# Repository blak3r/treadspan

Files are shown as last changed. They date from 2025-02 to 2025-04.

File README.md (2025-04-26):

# TreadSpan (the app for Treadmill Desk User's) 

With your hands stationary on a keyboard, watch based tracking methods don't work.  If your treadmill 
manufacturer offers an app, it requires you to log each session individually. TreadSpan solves this problem
and makes it easy to track all your steps taken from your Treadmill Desk. 

People that work at Treadmill Desks have different needs than those who use a treadmill for running. TreadSpan is the answer.

Everything about this solution is Open Source (mobile app, firmware, and hardware).  Together we can extend TreadSpan to 
support more treadmills. 

## Demo Video
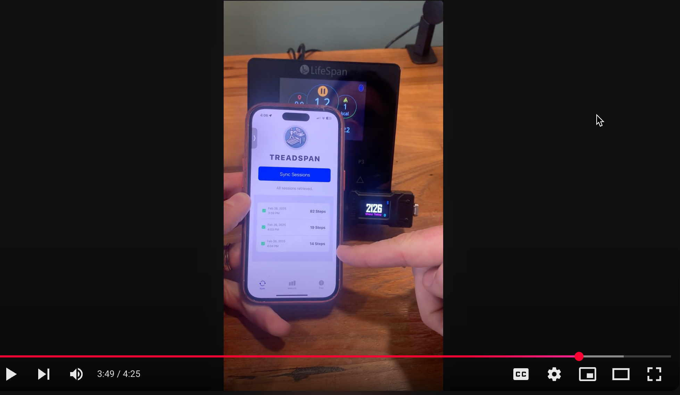
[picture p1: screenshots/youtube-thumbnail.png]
(https://youtu.be/KdCkAAa3uqI)


## My Story

When I upgraded my Treadmill, I purchased the [TR1200](https://amzn.to/4bbn8ok) from LifeSpan Fitness, in part 
because the manufacturer had created a mobile app which would allow you to log your steps and it would integrate with
Apple HealthKit. 
It sounded like the perfect solution. But, unfortunately the implementation of their mobile app was poor to say the least.
The biggest issue, was you had to open their clunky app to sync every session individually. 
Anytime, I went to the bathroom, answered the door, or grabbed a snack, I'd have to open the app, stop my train of 
thought on what i was doing, and log the steps.  I was sorta baffled. My bathroom scale logs my weight each time I step 
on it and stores each entry to it's internal memory. It patiently waits for me to open the mobile app and then it logs
all the unsynced entries to HealthKit in one go.

That's what this project aimed todo.  Make my walking pad as convenient as my bathroom scale. 
And with about $20 and 10 minutes of time, you can set this up too and free your mind from the chore of logging your
steps.

## Instructions

1. Buy this [~$17 ESP32 Module](https://amzn.to/43eFNhn). (See Hardware section for more options)
2. Install the [USB Serial drivers.](https://www.silabs.com/developer-tools/usb-to-uart-bridge-vcp-drivers?tab=downloads)
3. Load TreadSpan firmware / configure wifi, by [opening this page in Chrome](https://blak3r.github.io/treadspan-web-installer/). Support Video here: https://youtu.be/1UJMbb7URYI
5. Install the "TreadSpan" app on your iOS Device from the AppStore.
6. Open the app and follow instructions.

After the firmware is loaded in step 3, you can disconnect the module from your computer and can power it using any 
old USB-C cable/charger you have laying around.  You don't need to have it even visible on your desk, you could stuff it
in a cable tray under your desk if you really wanted to. 

## Hardware

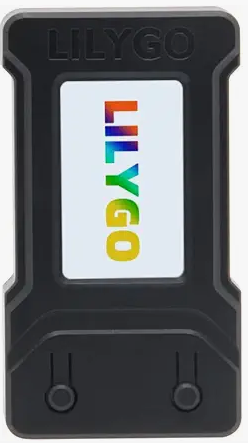
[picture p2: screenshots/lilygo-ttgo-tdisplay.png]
(https://amzn.to/43eFNhn)


* [Option 1: comes with a case - LILYGO ESP32 T-Display Module for Arduino CH9102F Chip TTGO Development Board with Shell Version](https://amzn.to/43eFNhn)
* [Option 2: no case - LILYGO ESP32 T-Display Module for Arduino CH9102F Chip TTGO Development Board NO Case](https://amzn.to/43eFNhn)

The case version has a much longer shipping estimate.  I've ordered it twice and they come within a week despite saying 2-3 weeks.
In Feb 2025, the case version was \$17 + \$9.50 shipping and the no case version is \$20 with free shipping. 
If you have a 3D printer and are impatient you can [print the case from these files](https://github.com/Xinyuan-LilyGO/TTGO-T-Display/tree/master/3d_file). 

If the links provided have gone bad, here is what you're looking to buy.
* Brand: LilyGo
* Chipset: ESPRESSIF-ESP32    <-- Notice it does NOT end with S3
* Model: TTGO T-Display
* Flash: 16MB
* Display: IPS ST7789V 1.14 Inch

DO NOT BUY THESE SIMILAR OPTIONS:
* T-Display-S3 AMOLED ESP32-S3 with 1.91 Inch RM67162 Display TTGO Development Board Wireless Module
* T-Display S3 ESP32-S3 1.9-inch ST7789 LCD Display Touchable Screen TTGO Wireless Module Welding Pin Development Board
* T-Display-S3-Long 16MB Flash ESP32-S3 TTGO Development Board with 3.4-inch Touch Display TFT LCD Wireless Modules

Technically, any ESP32 based Arduino should work.  I have loaded it on Arduino Nano ESP32 and The suggested hardware is nice since it has an LCD on it so it'll 
be helpful if you don't have wifi configured properly... or want to know how many sessions are on the device etc.

## Mobile App Features
- It's a barebones application that fetches all logged sessions from the arduino module aka the chip and adds them to HealthKit.  It does this in one step, no need to do the sync to apple health separately.
- It doesn't require you to create an account / login. No information is shared with 3rd Parties (other then Apple HealthKid)!
- It also has some visualizations that are very similar to the step graphs in Apple Health but it'll break out steps taken on your treadmill  
  vs. steps logged organically through a watch or iphone.

<table>
<tr>
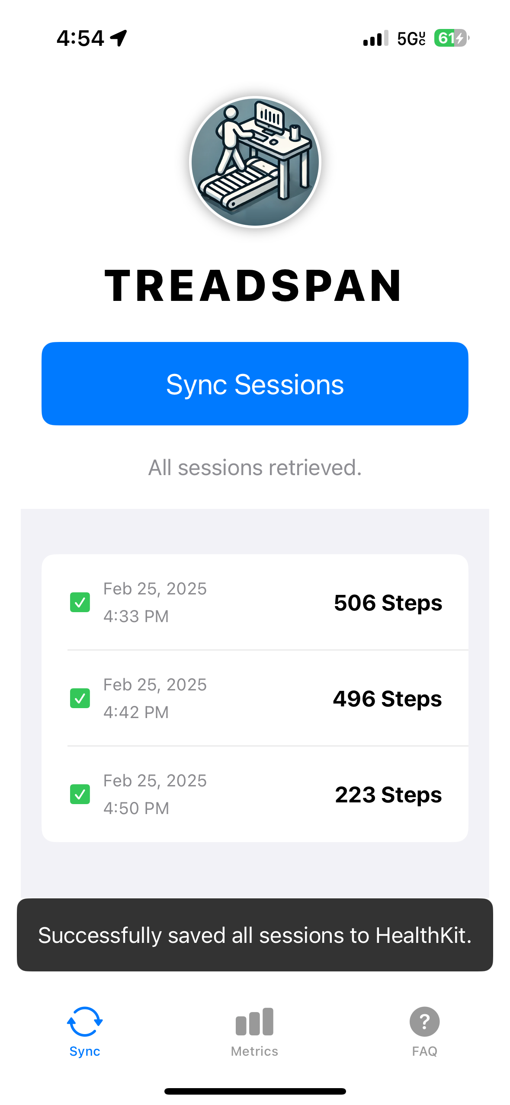
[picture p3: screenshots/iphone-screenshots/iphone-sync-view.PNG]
<td></td>
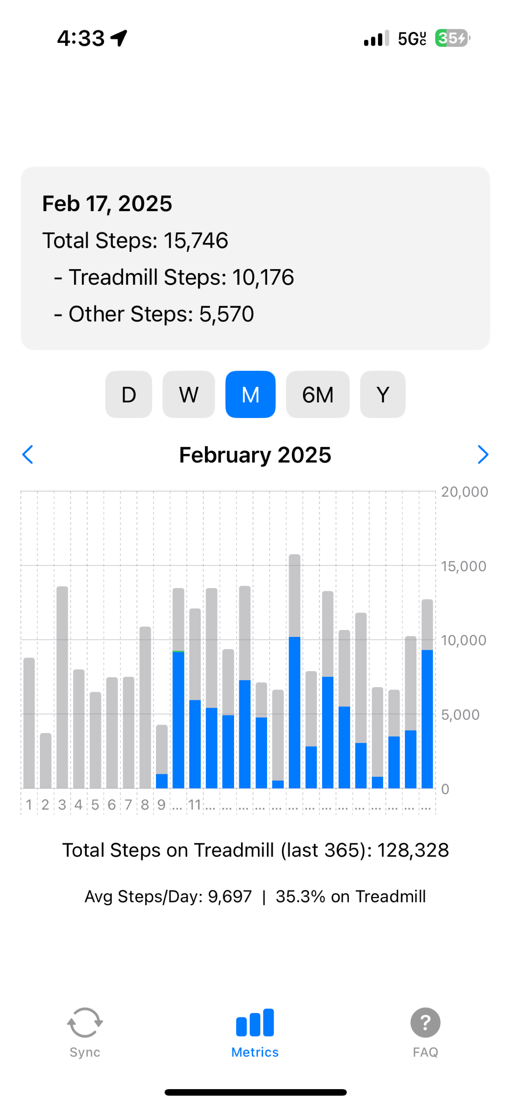
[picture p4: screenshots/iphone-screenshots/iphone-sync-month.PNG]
<td></td>
</tr>
</table>

## How it Works

A bunch of Bluetooth Low Energy (BLE) protocols.

Treadmill --(BLE)--> "The ESP32 Chip" --(BLE)--> TreadSpan Mobile App

First, the ESP32 Chip mimics the official Manufacturers App (LifeSpan Fit, UREVO, Sperax, etc) to pull the status 
of the treadmill / how many steps from in realtime.  It detects when sessions starts and stops and saves each session to it's internal memory 
with timestamps. The ESP32 also is running as a BLE Peripheral device that advertises itself to the Mobile App.

Second, the TreadSpan mobile app searches for TreadSpan hardware and will pull any sessions from it.  It then logs those
sessions to Apple HealthKit so your treadmill steps make it's way in.  This allows you to get an accurate view of steps taken
per day from both your treadmill and steps you organically accumulate walking in RL. 

## Development Environment Setups

This section is for developers that want to build the software / tweak things.
I hope that people will write custom firmware for other treadmills that leverage the same BLE protocol so they can leverage
the mobile app without modification.

The source code to the mobile app is available in the ios-app folder.

### ESP32 Firmware (Setup Arduino Development Environment).

NOTE: the project is currently able to work with both Arduino IDE and platformio.
If you don't have a hard preference, i'd recommend platformio as I'm moving in that direction and 
I believe it's actually faster to setup .

1. Install Arduino IDE.
2. Setup Arduino IDE for ESP32 support. See [this guide.](https://randomnerdtutorials.com/installing-the-esp32-board-in-arduino-ide-windows-instructions/)
3. Open the treadspan.ino file in the arduino folder.
4. You'll need to install these libraries:
   * Nimble (v2.2.3)
   * TFT_eSPI (2.5.43) - After you install this library, you'll have to edit User_Setup.h and User_Setup_Select.h as shown in [this image](/screenshots/TFT_eSPI_Setup.png).
   * RTCLib.h (2.1.4) - Only needed if you're using an RTC chip
5. Default Upload Speed of 921600 would not work for me.  I'd get a packet error.  Goto `Tools->Upload Speed` and select `460800`
6. Change the partition Scheme `Tools->Partition Scheme` to `Minimal SPIFFS (1.9MB APP with OTA/190KB SPIFFS)`
7. Depending on your hardware edit `#define`'s at the top of the file. 

### How do I add support for a new treadmill?
It's pretty easy! You only need to modify the arduino code.  The mobile app is universal.  I outlined some steps I used
for reverse engineering the Lifespan Fitness BLE protocol in the [Protocol Analysis](/protocol-analysis/README.md) Folder.

1. Create a new `TreadmillDevice`, LifespanOmniConsoleTreadmillDevice is an example that uses Bluetooth Low Energy.
2. Towards the top of treadspan.ino add a #define to select it, and then add to the `#if defined(OMNI_CONSOLE_MODE)`

The TreadmillDevice interface is such that you have public methods for `setupHandler()` and `loopHandler()` which are called.  You write
the code to detect when treadmill sessions start / stop and call the `sessionStartedDetected` and `sessionEndedDetected` methods.
Your `loopHandler()` method should not block the main loop, use callback methods and state variables appropriately.

### iOS Mobile App

The full source for the mobile app is provided in the `ios-app` folder. You'll need to have a Mac, install XCode, do things like create a developer certificate, and put your iphone into developer mode.  There are plenty of guides on this out there.

## Protocol Analysis
If you're interested in learning more about the reverse engineering of protocol attempts. Then, look in the [Protocol Analysis](/protocol-analysis/README.md) folder.
Here I include raw captures of the traffic over both the serial port and BLE as well as my notes from reversing the protocols.

## Contributors Welcome

- Add support for more treadmill brands. 
- Port the iOS App to Android. (AI tools should be able to do most of it)
- If someone wanted to sell preprogrammed Lily-Go T-Displays -or- sell special hardware versions (such as those with an RTC so wifi isn't needed)
  or one with serial port passthrough for non bluetooth solutions. I'd link to your store. 
- Non-technical folks, help spread the news on reddit and other social media sites.

## FAQS

### Is there an Android Version?
No, I'm hoping that someone in the community that has an Android phone will step up and assist. 
I'm fairly confident if you have any development skills and can use
an AI Tool like ChatGPT it wouldn't be difficult to port.  You would providing the SyncView.swift file and telling it to implement the 
BLE protocol. (The Metrics View is what took the vast majority of time to develop through trial and error and it's not core functionality).

### I have the LifeSpan Retro Console, Can I use this solution?
In theory, yes.  It is possible to get the steps through the serial port. I have implemented it and used it for some time.  
The downside of this approach is you need more complicated hardware and if you're not careful, there is a possibility that you could damage your treadmill if you 
don't connect things correctly.

The hardware is more complicated because you have to create small circuit board that will sniff the serial port traffic.

Here's the schematic
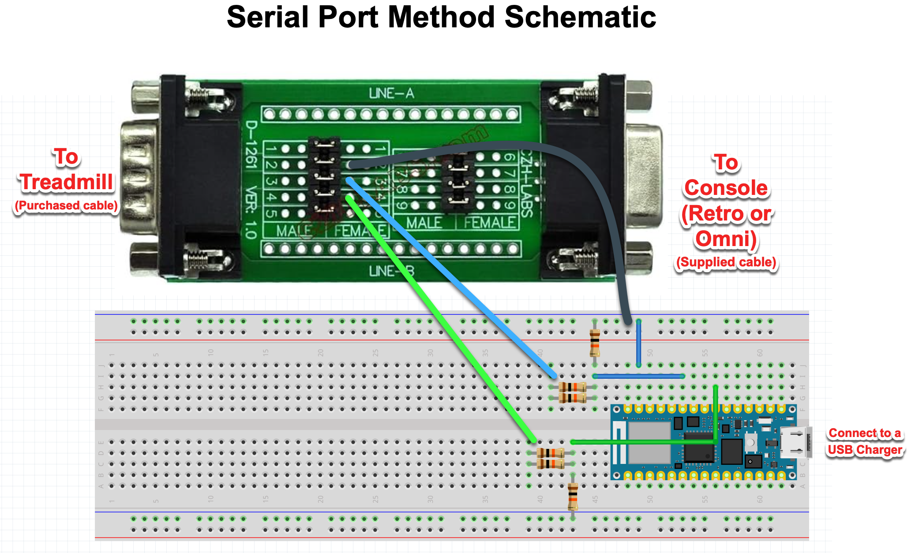
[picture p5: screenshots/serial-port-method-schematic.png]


Picture showing an early version I wrote that used Arduino ESP32 and a Character LCD.
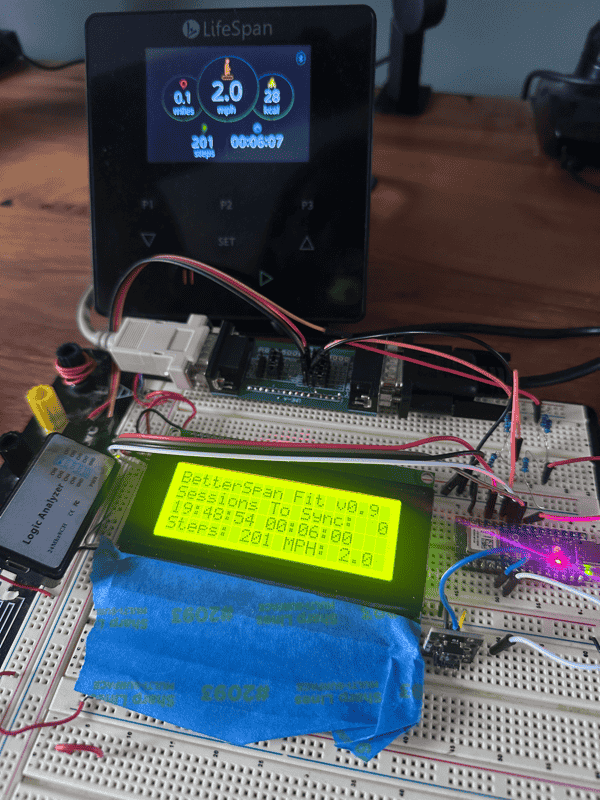
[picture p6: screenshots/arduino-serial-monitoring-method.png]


### Can I use this in an Office Environment, where there are lots of treadmills?
Not supported at the moment, if you want this, please let me know.  it would require adding some additional configuration
options to limit which devices it tries to connect with.  This solution 
was designed to make it as easy as possible to get working so it scans for devices matching names... having multiple
treadmill consoles or multiple arduinos programed in range is going to cause unpredicatable/unhandled results. 

### Why does the device require WiFi?

The device needs WiFi solely to maintain an accurate clock via NTP (Network Time Protocol), 
which is essential for correctly timestamping multiple stored sessions. Believe me, I didn't want to
introduce this extra setup step, but it’s necessary to ensure reliable session tracking. 
See this discussion thread where I outline other options considered: <https://github.com/blak3r/treadspan/discussions/3>

### Is it possible to control treadmill through mobile app?
I have not found anyway to control the treadmill through the BLE protocol.
It is theoretically possible to write commands to the treadmill via the serial protocol.
But, realistically you can't unless you were willing to sacrifice your existing console and only 
control it through the mobile app (you would also need the more complicated hardware setup and custom firmware).

## TODOs (Things actively working on)
HIGH
- ~~put code in place for fixing duration if time not set at start (mobile app shouldnt crash)~~
- ~~did i remove the reconnectWifiIfNecessary(); in periodicNtpUpdate~~
- NTP... go to the config_time method?
- Mobile App - Display total steps 
- FTMS - need a means of converting distance --> steps.
- Can I reduce backlight?

MED
- ~~WIFI Reconnect code on Arduino.~~
- Future proof the BLE protocol by adding a few additional options.
-- Payload Version
-- Ability to include distance, calories, average speed, etc if we wanted to log workouts also.
-- ~~Send time to device, Would be useful for an RTC based version.~~

LOW
- TEST: What would happen if you just turned off the treadmill while a session was active... need something to timeout if no data serial commands or BLE commands come in for a while for a while.
- Increase eeprom size to allow for more sessions?
- Could further optimize the serial code to prevent losing commands... but i'm not sure it going to make a difference.
- Create a means to configure the WiFi (over BLE protocol in IOS App).
- Mobile App --> Arduino Nano ESP32 takes a lot longer than LilyGo.  Not sure it matters much but seems odd. 
- See if we can compress space down so partition scheme doesn't need modified.

## Misc Resources

* https://docs.google.com/spreadsheets/d/1Oihy89PCLrDhiFWW2XuBikO9wjaKsS5WaEMcrmGne-E/edit?pli=1&gid=0#gid=0 - Big list of treadmills
* https://kinni.co/devices/ - Kinni's list of FTMS devices.
* https://github.com/lefty01/ESP32_TTGO_FTMS - Don't have a compatible treadmill and willing to hack around? See this project.

## Get Help / Support

If you have a question go here: https://github.com/blak3r/treadspan/discussions
If you want to report a bug go here: https://github.com/blak3r/treadspan/issues

## Supported Treadmills
[UREVO E1L](https://amzn.to/4iwcj29)
[TR1200](https://amzn.to/4bbn8ok)
* note there are affiliate links.

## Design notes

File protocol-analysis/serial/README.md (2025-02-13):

# Serial Protocol Reverse Engineering

This folder contains log files and analysis scripts wrote to reverse engineer the serial protocol between the treadmill
and consoles.  The log files here are for the "Omni Console" and a TR1200B.  Although, I suspect that since the retro
console and the omni console are backwards compatible... they should e substantially similar.  
(But, this remains unconfirmed)

To get this log file, I wrote a Serial Debug mode in the arduino app which output each command received.

## Timestamped Events.

I manually recorded the timestamps of when I pressed various buttons on the console to start and stop the treadmill.
You can use this log here in coordination with <treadmill-serial-comms-log.txt> to further evaluate if you want.

20:29:11 Started Treadmill - 0.4 MPH
20:29:35 Increased speed +0.1 --> 0.5 MPH
20:29:40 Increased speed +0.1 --> 0.6 MPH
20:29:59 Decreased Speed -0.1 --> 0.5 MPH
20:30:25 Pressed Preset #2, increased speed to 1.2 MPH
20:30:40 Pressed Preset #3, increased speed to 2.0 MPH
20:31:20 (No speed changes, but Steps = 91, Calories = 7)
20:31:45 Pressed Pause Button, 125 Steps, 9 Cal, 2:35min elapsed.
20:32:20 Pressed Pause Button again --> Console displays the workout summary.
20:32:36 Pressed Pause Button 3rd time --> Put console into standby (displays clock big)

## Hardware misc
Baud Rate: 4800, 8-N-1
Logic Level, TTL (0-5V);

Pin Label
1   +12V - but only when the console is on / awake.
2   GND
3   Treadmills TX Pin (Omni Console's RX) - It's a UART with TTL (5v logic levels)
4   Treadmills RX PIN (Omni Console's TX) - TTL Logic levels.
5   Yellow 5V, either supply, or data that mostly remains high (multimeter fluctuates from 5.03 to 5.04 V or so)
Not able to comment on 6-9 but don't think it matters it's 3 and 4 that i care about.

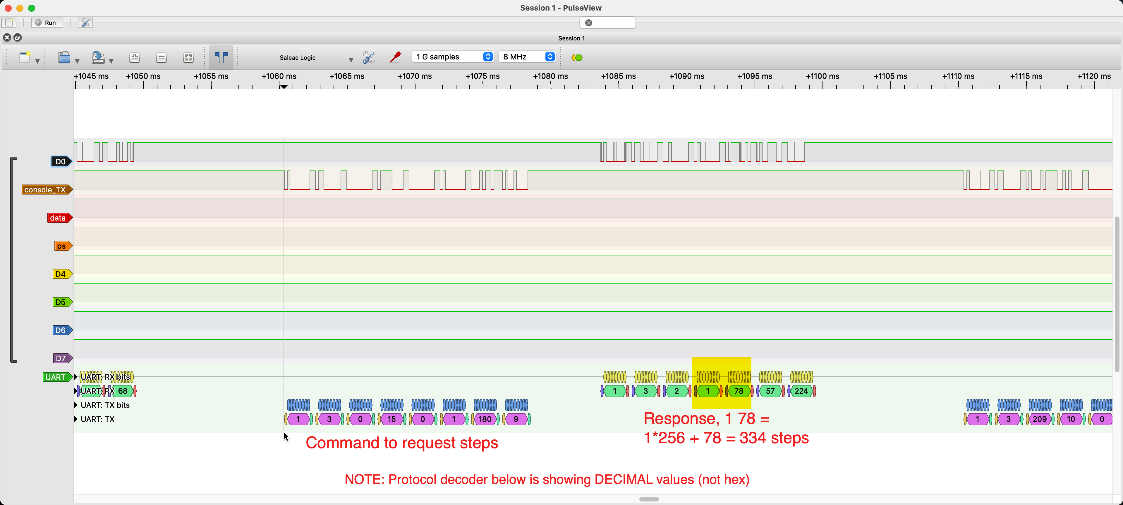
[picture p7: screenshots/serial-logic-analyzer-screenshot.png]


In the log files lines that say "REQ  :" are what came in on PIN 4.  The console sends command requests to the treadmill
and the treadmill responds to the requests.  Likewise, `RESP:` lines are what came in on pin 3 and were transmitted from 
the treadmill.

## What I Learned

REQs starting with 1 6 0 10 = are the speed - the treadmill just sends back the exact same payload as like a confirmation.
REQs starting with 1 3 0 15 = STEPS

There are some special commands that happen when you start the treadmill or press pause... 
They do `1 6 0 1` and `1 6 0 2` (see below)... but i found I didn't care about that as you can detect the treadmill is stopped
with `1 6 0 10 0 50 40 29`.  I found that my arduino code was semi unreliable in capturing every single command it would need
a fair amount of optimization to not miss a command every once in a while so relying on the commands that are sent over
and over seemed more reliable.  I do not know what the other commands do but they seem to always be the same so i assume it's
reporting versioning information.  

Steps are computed in the treadmill base. Everything else, like the session time, the speed, the calories are all computed in the console
and not shared over the wire.  

The other commands I don't know... but unfortunately, it doesn't appear that over the wire is:
* Wall time, (the time is set and stored in the console) and is never seems to be shared with treadmill.  It sort of makes sense as i cant see any reason... 
* Calories
* Time of session

## NOTEPAD - my "lab" notes.

20:29:11 - Started the treadmill (startup speed was 0.4).
Time coincides with a unique request of 1 6 0 1
20:29:11 REQ : 1 6 0 1 0 1 25 202
20:29:11 RESP: 1 6 0 1 0 1 25 202

20:31:45 - PAUSED
Got a unique payload also!
20:31:45 REQ : 1 6 0 2 0 1 233 202
20:31:45 RESP: 1 6 0 2 0 1 233 202

20:29:10 REQ : 1 6 0 15 0 0 185 201   <--- tracks with when i
20:31:45 REQ : 1 6 0 15 0 0 185 201   <--- tracks with when i stopped it.
20:31:46 REQ : 1 6 0 15 0 0 185 201
20:31:46 REQ : 1 6 0 15 0 0 185 201

## SPEED CHANGE ANALYSIS

### Pressed UP Arrow to go from 0.4-->0.5
20:29:35 REQ : 1 6 0 10 0 94 40 48
20:29:35 RESP: 1 6 0 10 0 94 40 48
20:29:35 REQ : 1 6 0 10 0 117 104 47
20:29:35 RESP: 1 6 0 10 0 117 104 47

### Increased by pressing +1 to go to 0.6
20:29:40 REQ : 1 6 0 10 0 117 104 47
20:29:40 RESP: 1 6 0 10 0 117 104 47
20:29:40 REQ : 1 6 0 10 0 141 105 173
20:29:40 RESP: 1 6 0 10 0 141 105 173

### Decreased by pressing Minus Arrow (0.6 --> 0.5)
20:29:58 REQ : 1 6 0 10 0 141 105 173
20:29:58 RESP: 1 6 0 10 0 141 105 173
20:29:59 REQ : 1 6 0 10 0 117 104 47
20:29:59 RESP: 1 6 0 10 0 117 104 47

### Pressed Preset button 0.5 --> 1.2
20:30:24 REQ : 1 6 0 10 0 117 104 47
20:30:24 RESP: 1 6 0 10 0 117 104 47
20:30:25 REQ : 1 6 0 10 1 26 41 147
20:30:25 RESP: 1 6 0 10 1 26 41 147

### Preset from 1.2 -> 2.0mph
20:30:40 REQ : 1 6 0 10 1 26 41 147
20:30:40 RESP: 1 6 0 10 1 26 41 147
20:30:40 REQ : 1 6 0 10 1 214 41 198
20:30:40 RESP: 1 6 0 10 1 214 41 198

### STOPPED IT...
20:31:45 REQ : 1 6 0 10 1 214 41 198
20:31:45 RESP: 1 6 0 10 1 214 41 198
20:31:45 REQ : 1 6 0 10 0 50 40 29
20:31:45 RESP: 1 6 0 10 0 50 40 29

Here's another view of the 1 6 0 commands..
55 20:28:59 REQ : 1 6 0 10 0 50 40 29
1 20:29:10 REQ : 1 6 0 10 0 94 40 48
1 20:29:10 REQ : 1 6 0 15 0 0 185 201
1 20:29:11 REQ : 1 6 0 10 0 94 40 48
1 20:29:11 REQ : 1 6 0 1 0 1 25 202
123 20:29:11 REQ : 1 6 0 10 0 94 40 48
25 20:29:35 REQ : 1 6 0 10 0 117 104 47
93 20:29:40 REQ : 1 6 0 10 0 141 105 173
130 20:29:59 REQ : 1 6 0 10 0 117 104 47
79 20:30:25 REQ : 1 6 0 10 1 26 41 147
326 20:30:40 REQ : 1 6 0 10 1 214 41 198
1 20:31:45 REQ : 1 6 0 10 0 50 40 29
1 20:31:45 REQ : 1 6 0 15 0 0 185 201
1 20:31:45 REQ : 1 6 0 10 0 50 40 29
1 20:31:45 REQ : 1 6 0 2 0 1 233 202
1 20:31:46 REQ : 1 6 0 10 0 50 40 29
1 20:31:46 REQ : 1 6 0 15 0 0 185 201
1 20:31:46 REQ : 1 6 0 10 0 50 40 29
1 20:31:46 REQ : 1 6 0 15 0 0 185 201

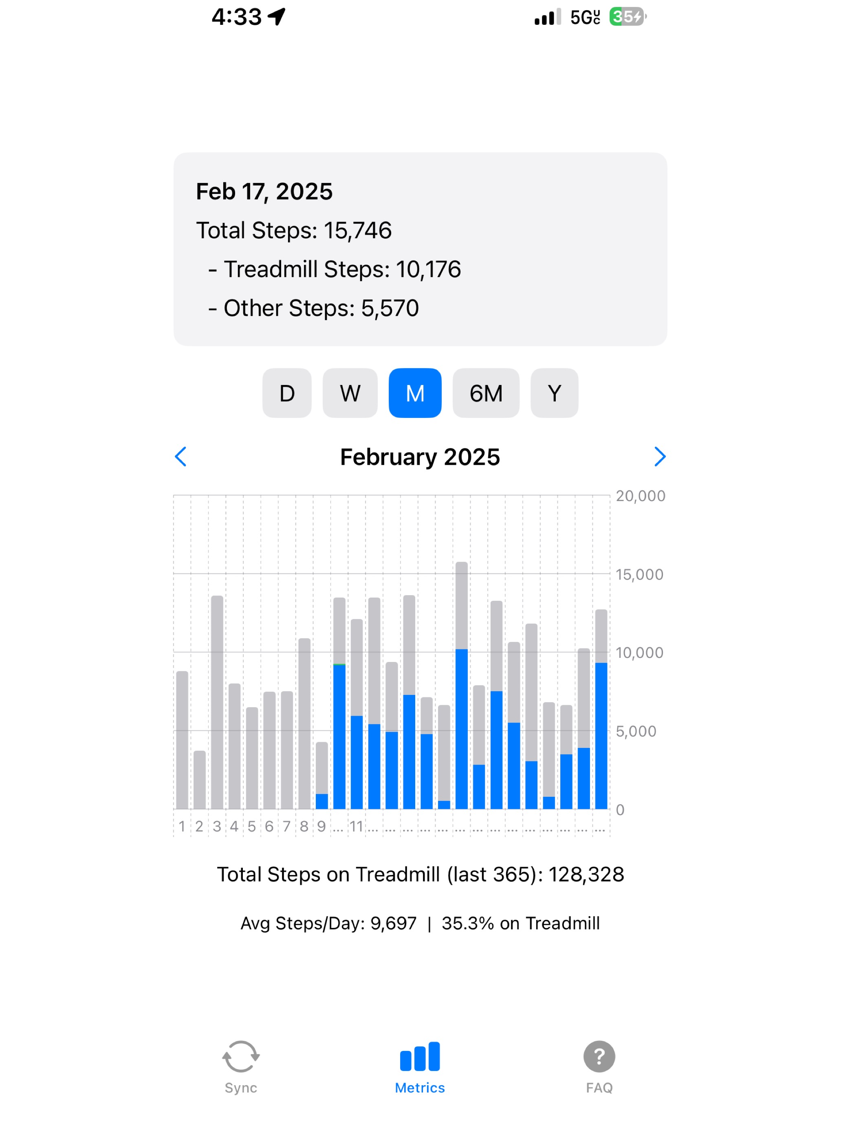
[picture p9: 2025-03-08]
screenshots/ipad-screenshots/month-1242.jpg

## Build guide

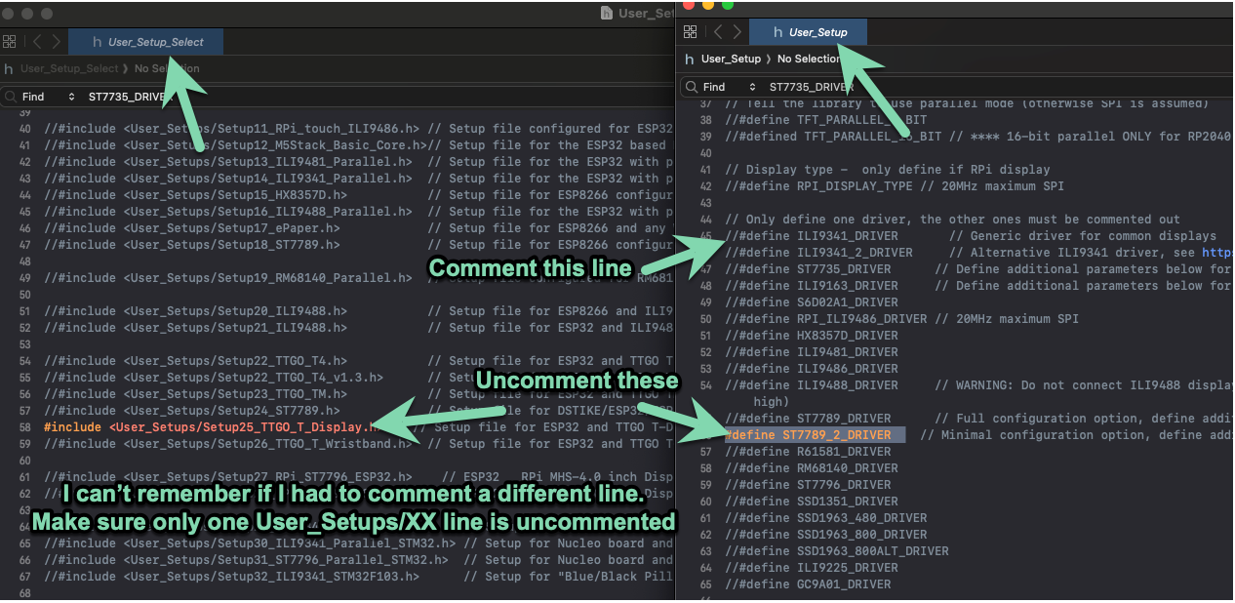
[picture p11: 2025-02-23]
screenshots/TFT_eSPI_Setup.png

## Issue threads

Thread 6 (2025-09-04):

App store

Timu5, 2025-09-04:
Is this app still on app store? I'm unable to find it

blak3r, 2025-09-20:
I just tried on a friends iPhone and was able to find it.

On Wed, Sep 17, 2025 at 6:38 AM Mateusz Muszyński ***@***.***>
wrote:

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

Timu5, 2025-09-21:
Can you provide a link? I'm located in eu, are you sure your app is available worldwide?

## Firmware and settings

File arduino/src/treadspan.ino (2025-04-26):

/*****************************************************************************
 * Treadmill Session Tracker on ESP32
 *
 * History:
 *   2025-03-01   0.9.6 - First release, BLE + TFT
 *   2025-03-15   1.0.7 - HW RTC Options, time setting via mobile app.
 *   2025-03-23   1.1.8 - FTMS Device / Autodetect
 *.  2025-04-06.  1.1.9 - Working FTMS, worked with UREVO E1L
 *   2025-04-08.  1.1.10- NimBLE updated to 2.2.3.
 *   2025-04-19   1.2.11- Platformio layout / UREVO Protocol.
 * Author: Blake Robertson
 * License: MIT
 *****************************************************************************/

#include <Arduino.h>

#include <WiFi.h>
#include <WiFiUdp.h>
#include <NimBLEDevice.h>
#include <EEPROM.h>
#include <sys/time.h>
#include <time.h>
#include "TreadmillDevice.h"
#include "HasElapsed.h"


/******************************************************************************************
 *                                      CONFIGURATION
 ******************************************************************************************/

#define FW_VERSION "v1.2.11"

/******************************************************************************************
 * 🏃 TREADMILL MODE SELECTION 🏃
 * Uncomment the mode that matches your treadmill setup.
 ******************************************************************************************/

//#define OMNI_CONSOLE_MODE 1     // 🔵 Use BLE for Sessions (Requires OMNI Console)
//#define RETRO_MODE 1            // 🟢 Use Serial Port for Sessions (Requires special hardware)
//#define FTMS_MODE 1             // Most Common - supports all treadmills which implemented FTMS
#define UREVO_MODE 1            // UREVO's proprietary service that provides step count, uses FTMS control characteristic in tandem.

/******************************************************************************************
 * ⚙️ GENERAL SETTINGS ⚙️
 * Adjust these as needed for debugging, display, and RTC configurations.
 ******************************************************************************************/

#define ENABLE_DEBUG 1                          // 🔍 Allows logs to be printed to Serial
#define VERBOSE_LOGGING 1                       // 🔍 Enable verbose BLE/Serial logging (set to 1 for more logs)
#define HAS_TFT_DISPLAY 1                       // 🖥️ Enable TFT display (LilyGo hardware)
#define LOAD_WIFI_CREDENTIALS_FROM_EEPROM 1     // 📡 Load WiFi credentials from EEPROM
#define INCLUDE_IMPROV_SERIAL 1                 // ⚡ Configure WiFi via Flash Installer (must be disabled when GET_TIME_THROUGH_NTP is undefined)
#define GET_TIME_THROUGH_NTP 1                  // 📡 Enables WIFI to get time via NTP
//#define HAS_RTC_DS3231                        // ⏰ UNCOMMON: Enable support for DS3231 Real-Time Clock (RTC)
//#define SESSION_SIMULATION_BUTTONS_ENABLED 1  // 🕹️ Enable test buttons for session simulation
//#define LCD_4x20_ENABLED 1                    // 🖨️ UNCOMMON: Enable 4x20 I2C LCD screen support

#ifndef LOAD_WIFI_CREDENTIALS_FROM_EEPROM
  const char* ssid = "Angela";
  const char* password = "iloveblake";  // 🔒 Example WiFi credentials for demonstration
#endif

#ifdef SESSION_SIMULATION_BUTTONS_ENABLED
  #define BUTTON_PIN 2  // 🔘 D2 - Press to simulate a treadmill session
  #define CLEAR_PIN 0   // 🔘 D3 - Press to clear all sessions in EEPROM
#endif

/******************************************************************************************
 * 🚨 DO NOT MODIFY BELOW THIS LINE 🚨
 * Internal configurations. Modify at your own risk.
 ******************************************************************************************/

// DEPENDENT LIBRARIES
#ifdef LCD_4x20_ENABLED
  #include <Wire.h>
  #include <LiquidCrystal_I2C.h>
  LiquidCrystal_I2C lcd(0x27, 20, 4);
#endif

#if INCLUDE_IMPROV_SERIAL
  #include <ImprovWiFiLibrary.h>
  ImprovWiFi improvSerial(&Serial);
#endif

#ifdef HAS_TFT_DISPLAY
  #include <SPI.h>
  #include <TFT_eSPI.h>
  TFT_eSPI tft = TFT_eSPI();
  TFT_eSprite sprite = TFT_eSprite(&tft);

  #define TOP_BUTTON 35
  #define BOT_BUTTON 0
#endif

#if !defined(VERBOSE_LOGGING)
  #define VERBOSE_LOGGING 0
#endif

#if defined(GET_TIME_THROUGH_NTP)
  const bool getTimeThroughNtp = true;
#else
  #if defined(INCLUDE_IMPROV_SERIAL)
    #error "You can't have INCLUDE_IMPROV_SERIAL enabled when GET_TIME_THROUGH_NTP is not (you're essentially configuring wifi that isn't enabled)"
  #endif
  const bool getTimeThroughNtp = false;
#endif

#if !defined(HAS_RTC_DS3231) && !defined(GET_TIME_THROUGH_NTP)
  #error "You need to have at least one defined TIME method, NTP or RTC"
#endif

#include "TreadmillDevice.h"
#include "globals.h"

#include "TreadmillDeviceLifespanOmniConsole.h"
#include "TreadmillDeviceLifespanRetroConsole.h"
#include "TreadmillDeviceFTMS.h"
  
#if defined(OMNI_CONSOLE_MODE)
  #include "TreadmillDeviceLifespanOmniConsole.h"
  TreadmillDevice *treadmillDevice =  new TreadmillDeviceLifespanOmniConsole();
#elif defined(RETRO_MODE)
  #include "TreadmillDeviceLifespanRetroConsole.h"
  TreadmillDevice *treadmillDevice =  new TreadmillDeviceLifespanRetroConsole();
#elif defined(FTMS_MODE)
  #include "TreadmillDeviceFTMS.h"
  TreadmillDevice *treadmillDevice =  new TreadmillDeviceFTMS();
#elif defined(UREVO_MODE)
  #include "TreadmillDeviceUrevoProtocol.h"
  TreadmillDevice *treadmillDevice =  new TreadmillDeviceUrevoProtocol();
#else
  #error "You have not selected a TreadmillDevice Implementation."
#endif

#ifdef HAS_RTC_DS3231
  #include "RTClib.h"
  RTC_DS3231 rtc;
  boolean rtcFound = false;
  void setSystemTime(time_t); // forward declaration
  
  void setSystemTimeFromRtc() {
    Debug.printf("Pulling time from RTC");
    DateTime now = rtc.now();
    time_t unixTime = now.unixtime();
    setSystemTime(unixTime);
  }
  void periodicRtcDS3231TimeRetriever() {
    static HasElapsed rtcTimeRetreiverTimer(10*60*1000);
    // Check if 10 minutes have elapsed
    if (rtcFound && rtcTimeRetreiverTimer.isIntervalUp()) {
        setSystemTimeFromRtc();
    }
  }
#endif

// EEPROM Configuration
#define EEPROM_SIZE 512
#define MAX_SSID_LENGTH 32
#define SSID_INDEX 0
#define PASSWORDS_INDEX 32
#define SESSIONS_START_INDEX 64
#define SESSION_SIZE_BYTES sizeof(TreadmillSession)
#define MAX_SESSIONS ((EEPROM_SIZE - (SESSIONS_START_INDEX + 4)) / SESSION_SIZE_BYTES)



#include "./DebugWrapper.h"
DebugWrapper Debug;
bool wasTimeSet = false;

// BLE UUIDs
static const char* BLE_SERVICE_UUID = "0000A51A-12BB-C111-1337-00099AACDEF0";
static const char* BLE_DATA_CHAR_UUID = "0000A51A-12BB-C111-1337-00099AACDEF1";
static const char* BLE_CONFIRM_CHAR_UUID = "0000A51A-12BB-C111-1337-00099AACDEF2";
static const char* BLE_TIME_READ_CHAR_UUID = "0000A51A-12BB-C111-1337-00099AACDEF3";
static const char* BLE_TIME_WRITE_CHAR_UUID = "0000A51A-12BB-C111-1337-00099AACDEF4";

// BLE Peripheral Variables (modified for NimBLE)
NimBLEServer* pServer = nullptr;
NimBLECharacteristic* dataCharacteristic = nullptr;
NimBLECharacteristic* confirmCharacteristic = nullptr;
bool isMobileAppConnected = false;
bool isMobileAppSubscribed = false;
bool haveNotifiedMobileAppOfFirstSession = false;

int currentSessionIndex = 0;
int sessionsStored = 0;
bool clearedSessions = false;
bool areWifiCredentialsSet = false;

// NEW: Pointers to the new time characteristics
NimBLECharacteristic* timeReadCharacteristic = nullptr;   // NEW
NimBLECharacteristic* timeWriteCharacteristic = nullptr;  // NEW

// COMMON STATE VARIABLES (RETRO / OMNI)
uint32_t gSteps = 0;
uint16_t gCalories = 0;         
uint32_t gDistance = 0;
uint32_t gDistanceInMeters = 0;        
bool gIsTreadmillActive = 0;
float gSpeedFloat = 0;
uint16_t gDurationInSecs = 0;

volatile bool gResetRequested = 0;

//int avgSpeedInt = 0;      // only omni console mode.
//float avgSpeedFloat = 0;  // only omni console
//int speedInt = 0;

// NEW: Global variables for tracking today's steps
String lastRecordedDate = "";       //YYYY-MM-DD
unsigned long totalStepsToday = 0;  //
TreadmillSession gCurrentSession;


//------------------- COMMON TIME SETTING --------------------//
String getFormattedTimeYMD();
String getFormattedTimeHMS();
String getFormattedDate();
void tftWifiConnectingScreen(const char*);

/**
 * This is called by NTP Update and by
 * the Mobile App during syncs via the BLE Time Write Characteristic
 */
void setSystemTime( time_t epochTime) {
  #ifdef HAS_RTC_DS3231
    DateTime dt(epochTime);
    if( rtcFound ) {
      rtc.adjust(dt);
    }
  #endif

  struct timeval tv;
  tv.tv_sec = epochTime;
  tv.tv_usec = 0;
  settimeofday(&tv, NULL);

  Debug.printf("System time updated: %s %s %lu\n", getFormattedTimeYMD(), getFormattedTimeHMS(), (uint32_t) epochTime );

  wasTimeSet = true;
}

// ---------------------------------------------------------------------------
// Wifi / NTP
// ---------------------------------------------------------------------------
#ifdef GET_TIME_THROUGH_NTP
  // NTP Configuration
  const char* ntpServer = "pool.ntp.org";
  const int ntpPort = 123;
  WiFiUDP ntpUDP;

  void trimString(char* str, int maxLength) {
    for (int i = 0; i < maxLength; i++) {
      if (str[i] == '\0') break;  // Stop at first null
    }
  }

  void loadWiFiCredentialsFromEEPROM(char* ssid, char* password) {
    for (int i = 0; i < MAX_SSID_LENGTH; i++) {
      ssid[i] = EEPROM.read(SSID_INDEX + i);
      if (ssid[i] == '\0') break;
    }
    ssid[MAX_SSID_LENGTH - 1] = '\0';

    for (int i = 0; i < MAX_SSID_LENGTH; i++) {
      password[i] = EEPROM.read(PASSWORDS_INDEX + i);
      if (password[i] == '\0') break;
    }
    password[MAX_SSID_LENGTH - 1] = '\0';

    Debug.printf("Loaded SSID: %s\n", ssid);
    Debug.printf("Loaded Password: %s\n", password);
  }

  bool loadWifiCredentialsIntoBuffers(char* ssidBuf, char* passwordBuf) {
    #if LOAD_WIFI_CREDENTIALS_FROM_EEPROM
      loadWiFiCredentialsFromEEPROM(ssidBuf, passwordBuf);
    #else
      strncpy(ssidBuf, ssid, sizeof(ssidBuf));  // Developer mode... ssid/password are hardcoded.
      strncpy(passwordBuf, password, sizeof(ssidBuf));
    #endif

    Debug.printf("ssidBuf[0]: %02X, len1 %d len2 %d\n", ssidBuf[0], strlen(ssidBuf), strlen(passwordBuf));

    return ssidBuf[0] != 0xFF && strlen(ssidBuf) > 0 && strlen(passwordBuf) > 0 && strlen(ssidBuf) < 31 && strlen(passwordBuf) < 31;
  }

  void screenWifiConnecting(void);  // forward declaration

  bool connectWifi(const char* ssid, const char* password) {
    #ifdef LCD_4x20_ENABLED
      lcd.clear();
      lcd.print("Connecting to WiFi");
    #endif

    Debug.printf("Connecting to WiFi... %s\n", ssid); 
    WiFi.begin(ssid, password);

    unsigned long startTime = millis();
    while (WiFi.status() != WL_CONNECTED && (millis() - startTime) < 7000) {
      #ifdef HAS_TFT_DISPLAY
        tftWifiConnectingScreen(ssid);
      #endif
      delay(100);
    }

    return WiFi.status() == WL_CONNECTED;
  }

  void reconnectWifiIfNecessary() {
    static HasElapsed reconnectWifiTimer(30000);

    if( WiFi.status() != WL_CONNECTED && areWifiCredentialsSet ) {
      if( reconnectWifiTimer.isIntervalUp() ) {
        Debug.printf("Int is up\n");
        Debug.printf("Lost WiFi connection, attempting to reconnect...\n");
        char ssidBuf[32], passBuf[32];
        loadWifiCredentialsIntoBuffers(ssidBuf, passBuf);
        connectWifi(ssidBuf, passBuf);
      }
    } else {
      reconnectWifiTimer.reset(); // reset it back to 30 so we don't immediately retry after losing connection.
    }
  }

  void sendNtpRequest(); // forward declaration

  // This callback is called when WiFi connects and gets an IP
  void WiFiEvent(WiFiEvent_t event, WiFiEventInfo_t info) {
    if (event == ARDUINO_EVENT_WIFI_STA_GOT_IP) {
      // START UDP
      ntpUDP.begin(ntpPort);
      delay(100);
      sendNtpRequest();  // initial time request
    }
  }                   

  void setupWifi() {
    char ssid[32], password[32];
    WiFi.onEvent(WiFiEvent);
    areWifiCredentialsSet = loadWifiCredentialsIntoBuffers(ssid, password);  // loads from SSID/PASS from file system or program memory depending on build configs.
    Debug.printf("areWifiCredentialsSet: %d\n", areWifiCredentialsSet);
    if (areWifiCredentialsSet) {
      connectWifi(ssid, password);
    } else {
    }
  }

  #define NTP_PACKET_SIZE 48
  byte ntpPacketBuffer[NTP_PACKET_SIZE];

  // Timer variables
  volatile unsigned long lastNtpRequest = 0;
  volatile unsigned long ntpUpdateInterval = 60*1000;  // eventually 600000 (10 mins), but start short for quick sync

  void sendNtpRequest() {
    Debug.printf("Sending NTP request...\n");

    memset(ntpPacketBuffer, 0, NTP_PACKET_SIZE);
    ntpPacketBuffer[0] = 0b11100011;  // LI, Version, Mode
    ntpPacketBuffer[1] = 0;           // Stratum
    ntpPacketBuffer[2] = 6;           // Polling Interval
    ntpPacketBuffer[3] = 0xEC;        // Peer Clock Precision

    // Send packet to NTP server
    ntpUDP.beginPacket(ntpServer, ntpPort);
    ntpUDP.write(ntpPacketBuffer, NTP_PACKET_SIZE);
    ntpUDP.endPacket();

   // configTime(0, 0, "pool.ntp.org");
    lastNtpRequest = millis();
  }

  void checkNtpResponse() {
    int packetSize = ntpUDP.parsePacket();
    if (packetSize >= NTP_PACKET_SIZE) {
      Debug.printf("NTP response received! size=%d\n", packetSize);

      ntpUDP.read(ntpPacketBuffer, NTP_PACKET_SIZE);
      ntpUDP.flush();
      unsigned long highWord = word(ntpPacketBuffer[40], ntpPacketBuffer[41]);
      unsigned long lowWord = word(ntpPacketBuffer[42], ntpPacketBuffer[43]);
      
      time_t epochTime = (highWord << 16 | lowWord) - 2208988800UL;  // Convert to UNIX time

      // Right after ntpUDP.read(ntpPacketBuffer, NTP_PACKET_SIZE);
      Debug.println("=== RAW NTP DATA ===");
      for (int i = 0; i < NTP_PACKET_SIZE; i++) {
        Debug.printf_noTs("%02X ", ntpPacketBuffer[i]);
      }
      Debug.println("\n====================");

      if( (uint32_t) epochTime == 0 || (uint32_t) epochTime == (uint32_t) 0xFFFFFFFF) {
        Debug.printf("Invalid packet received! %X", epochTime);
        return;
      }

      ntpUpdateInterval = (unsigned long) 60*10*1000;  // set to 10 minutes after first success
      setSystemTime(epochTime);
    }
  }

  void periodicNtpUpdateMainLoopHandler() {
    if (WiFi.status() == WL_CONNECTED) {
      if ((millis() - lastNtpRequest) >= ntpUpdateInterval) {
        ntpUpdateInterval = 10*60*1000;
        sendNtpRequest();
        delay(100);
      }
      else {
        checkNtpResponse();
      }
    }
    reconnectWifiIfNecessary();
  }
#endif // GET_TIME_THROUGH_NTP


String getFormattedTimeHMS() {
  time_t now = time(nullptr);
  if (now < 100000) {
    return "TBD, NTP sync";
  }

  struct tm timeinfo;
  localtime_r(&now, &timeinfo);

  char buffer[30];
  strftime(buffer, sizeof(buffer), "%H:%M:%S", &timeinfo);
  return String(buffer);
}

String getFormattedTimeYMD() {
  time_t now = time(nullptr);
  if (now < 100000) {
    return "???";
  }

  struct tm timeinfo;
  localtime_r(&now, &timeinfo);

  char buffer[30];
  strftime(buffer, sizeof(buffer), "%Y-%m-%d", &timeinfo);
  return String(buffer);
}


// ---------------------------------------------------------------------------
// EEPROM Layout & Session Struct
// ---------------------------------------------------------------------------
//  - [0...31]   : WiFi SSID
//  - [32..63]   : WiFi PASS
//  - [64..67]   : uint32_t sessionCount
//  - [68..end] : session data in blocks of 12 bytes each
//
// Each session block:
//    Byte 0..3  : start time (Big-endian)
//    Byte 4..7  : stop time  (Big-endian)
//    Byte 8..11 : steps      (Big-endian)

uint32_t getSessionCountFromEEPROM() {
  uint32_t count = 0;
  count |= (EEPROM.read(SESSIONS_START_INDEX + 0) << 24);
  count |= (EEPROM.read(SESSIONS_START_INDEX + 1) << 16);
  count |= (EEPROM.read(SESSIONS_START_INDEX + 2) << 8);
  count |= EEPROM.read(SESSIONS_START_INDEX + 3);

  if (count >= MAX_SESSIONS) {
    count = 0;
    Debug.println("DETECTED UNINITED EEPROM");
  }

  sessionsStored = count;
  return count;
}

void setSessionCountInEEPROM(uint32_t count) {
  sessionsStored = count;
  EEPROM.write(SESSIONS_START_INDEX + 0, (count >> 24) & 0xFF);
  EEPROM.write(SESSIONS_START_INDEX + 1, (count >> 16) & 0xFF);
  EEPROM.write(SESSIONS_START_INDEX + 2, (count >> 8) & 0xFF);
  EEPROM.write(SESSIONS_START_INDEX + 3, count & 0xFF);
  EEPROM.commit();
}

TreadmillSession readSessionFromEEPROM(int index) {
  TreadmillSession session;
  int startAddress = SESSIONS_START_INDEX + 4 + (index * SESSION_SIZE_BYTES);

  session.start = ((uint32_t)EEPROM.read(startAddress)     << 24) |
                  ((uint32_t)EEPROM.read(startAddress + 1) << 16) |
                  ((uint32_t)EEPROM.read(startAddress + 2) <<  8) |
                   (uint32_t)EEPROM.read(startAddress + 3);

  session.stop  = ((uint32_t)EEPROM.read(startAddress + 4) << 24) |
                  ((uint32_t)EEPROM.read(startAddress + 5) << 16) |
                  ((uint32_t)EEPROM.read(startAddress + 6) <<  8) |
                   (uint32_t)EEPROM.read(startAddress + 7);

  session.steps = ((uint32_t)EEPROM.read(startAddress + 8)  << 24) |
                  ((uint32_t)EEPROM.read(startAddress + 9)  << 16) |
                  ((uint32_t)EEPROM.read(startAddress + 10) <<  8) |
                   (uint32_t)EEPROM.read(startAddress + 11);

  return session;
}

void writeSessionToEEPROM(int index, TreadmillSession session) {
  int startAddress = SESSIONS_START_INDEX + 4 + (index * SESSION_SIZE_BYTES);

  EEPROM.write(startAddress, (session.start >> 24) & 0xFF);
  EEPROM.write(startAddress + 1, (session.start >> 16) & 0xFF);
  EEPROM.write(startAddress + 2, (session.start >> 8) & 0xFF);
  EEPROM.write(startAddress + 3, (session.start) & 0xFF);

  EEPROM.write(startAddress + 4, (session.stop >> 24) & 0xFF);
  EEPROM.write(startAddress + 5, (session.stop >> 16) & 0xFF);
  EEPROM.write(startAddress + 6, (session.stop >> 8) & 0xFF);
  EEPROM.write(startAddress + 7, (session.stop) & 0xFF);

  EEPROM.write(startAddress + 8, (session.steps >> 24) & 0xFF);
  EEPROM.write(startAddress + 9, (session.steps >> 16) & 0xFF);
  EEPROM.write(startAddress + 10, (session.steps >> 8) & 0xFF);
  EEPROM.write(startAddress + 11, (session.steps) & 0xFF);

  EEPROM.commit();
}

void printSessionDetails(TreadmillSession s, int index) {
  time_t startTime = (time_t)s.start;
  time_t stopTime = (time_t)s.stop;

  char startStr[26] = "Unknown";
  char stopStr[26] = "Unknown";
  ctime_r(&startTime, startStr);
  ctime_r(&stopTime, stopStr);

  if (startStr[strlen(startStr) - 1] == '\n') startStr[strlen(startStr) - 1] = '\0';
  if (stopStr[strlen(stopStr) - 1] == '\n') stopStr[strlen(stopStr) - 1] = '\0';

  Debug.printf("Session #%d:\n", index);
  Debug.printf("  Start: %s (Unix: %u)\n", startStr, s.start);
  Debug.printf("  Stop : %s (Unix: %u)\n", stopStr, s.stop);
  Debug.printf("  Steps: %u\n", s.steps);
}

void printAllSessionsInEEPROM() {
  uint32_t count = getSessionCountFromEEPROM();
  uint32_t printCount = (count > MAX_SESSIONS) ? MAX_SESSIONS : count;

  Debug.printf("\n--- EEPROM Debug: Found %u session(s) stored ---\n", count);
  if (count > MAX_SESSIONS) {
    Debug.printf("Printing only the first %u session(s)...\n", MAX_SESSIONS);
  }

  for (uint32_t i = 0; i < printCount; i++) {
    TreadmillSession s = readSessionFromEEPROM(i);
    printSessionDetails(s, i);
  }
  Debug.println("----------------------------------------------\n");
}

void recordSessionToEEPROM(TreadmillSession session) {
  uint32_t count = getSessionCountFromEEPROM();
  if (count >= MAX_SESSIONS) {
    Debug.println("EEPROM is full. Cannot store more sessions.");
    return;
  }
  writeSessionToEEPROM(count, session);
  setSessionCountInEEPROM(count + 1);
  EEPROM.commit();

  Debug.printf("Session stored at index=%u. Steps=%u\n", count, session.steps);

  // Update today's steps total
  String today = getFormattedDate();
  if (lastRecordedDate != today) {
    lastRecordedDate = today;
    totalStepsToday = 0;
  }
  totalStepsToday += session.steps;
}
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
void loop() {

  #ifdef INCLUDE_IMPROV_SERIAL
    improvSerial.handleSerial();
  #endif

  #ifdef GET_TIME_THROUGH_NTP
    periodicNtpUpdateMainLoopHandler();

        // Simple reconnect logic if WiFi credentials exist but WiFi is lost
    // static unsigned long lastWifiCheck = 0;
    // const unsigned long wifiCheckInterval = 10000; // 10 seconds
    // if (millis() - lastWifiCheck >= wifiCheckInterval) {
    //   lastWifiCheck = millis();
    //   if (areWifiCredentialsSet && (WiFi.status() != WL_CONNECTED)) {
    //     Debug.println("Lost WiFi connection, attempting to reconnect...");
    //     char ssidBuf[32], passBuf[32];
    //     loadWifiCredentialsIntoBuffers(ssidBuf, passBuf);
    //     connectWifi(ssidBuf, passBuf);
    //   }
   // }
  #endif

  #ifdef HAS_RTC_DS3231
    periodicRtcDS3231TimeRetriever();
  #endif

  #ifdef LCD_4x20_ENABLED
    periodicLcdUpdateMainLoopHandler();
  #endif

  #ifdef HAS_TFT_DISPLAY
    tftPeriodicMainLoopHandler();
  #endif

  #ifdef SESSION_SIMULATION_BUTTONS_ENABLED
    // Check button press
    if (buttonPressed) {
      buttonPressed = false;
      simulateNewSession();  // For dev testing only
    }

    // Clear sessions if CLEAR_PIN is LOW (do once)
    if (!clearedSessions && digitalRead(CLEAR_PIN) == LOW) {
      Debug.printf("CLEAR_PIN is LOW, clearing all sessions...\n");
      setSessionCountInEEPROM(0);
      EEPROM.commit();
      clearedSessions = true;
    }
  #endif

  if (isMobileAppConnected && isMobileAppSubscribed && !haveNotifiedMobileAppOfFirstSession) {
    haveNotifiedMobileAppOfFirstSession = true;
    currentSessionIndex = 0;
    Debug.printf("Mobile App subscribed, sending first session...\n");
    indicateNextSession();
  }

  treadmillDevice->loopHandler();

  delay(1);
}

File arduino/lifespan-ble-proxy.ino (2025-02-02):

/*****************************************************************************
 * Treadmill Session Tracker on ESP32
 * 
 * Demonstrates:
 *  - Storing/reading treadmill sessions in EEPROM (12 bytes each).
 *  - Advertising a BLE service with two characteristics:
 *      * Data Characteristic (was Indicate, now using NOTIFY).
 *      * Confirmation Characteristic (Write) -> Receives 0x01 acknowledgments.
 *  - Sending sessions one-by-one after client acknowledgment.
 *  - Clearing stored sessions in EEPROM after all have been sent (and ack'd).
 *  - Handling button presses to simulate new sessions via interrupt.
 *  - Printing session data on Serial at startup.
 *  - Clearing sessions if GPIO12 is HIGH.
 *  - NEW: Using descriptor callbacks to detect subscription instead of a fixed delay.
 *****************************************************************************/

#include <Arduino.h>
#include <BLEDevice.h>
#include <BLEServer.h>
#include <BLEUtils.h>
#include <BLE2902.h>
#include <EEPROM.h>
#include <time.h>  // For time() function (requires time sync for accurate local time)

// ---------------------------------------------------------------------------
// Configuration
// ---------------------------------------------------------------------------
#define EEPROM_SIZE        512
#define BUTTON_PIN         0     // Built-in flash button on many ESP32 dev boards
#define CLEAR_PIN          12    // If GPIO12 is HIGH, clear all sessions in EEPROM
#define MAX_SESSIONS       42    // Up to 42 sessions (12 bytes each) + 4 bytes for count
#define SESSION_SIZE_BYTES 12    // start(4) + stop(4) + steps(4)

static const char* BLE_SERVICE_UUID       = "12345678-1234-5678-1234-56789abcdef0";
static const char* BLE_DATA_CHAR_UUID     = "12345678-1234-5678-1234-56789abcdef1";
static const char* BLE_CONFIRM_CHAR_UUID  = "12345678-1234-5678-1234-56789abcdef2";

// ---------------------------------------------------------------------------
// Global Objects & Variables
// ---------------------------------------------------------------------------
BLEServer* pServer                = nullptr;
BLECharacteristic* dataCharacteristic    = nullptr;
BLECharacteristic* confirmCharacteristic = nullptr;

bool deviceConnected       = false;
bool oldDeviceConnected    = false;
bool subscribed           = false;    // If the central wrote 0x01 or 0x02 to the CCCD
bool haveNotifiedFirstPacket = false; // So we only do the initial send once

int currentSessionIndex    = 0; // Index of the next session to indicate

bool clearedSessions       = false; // Flag to ensure we only clear once if GPIO12 is HIGH

// ---------------------------------------------------------------------------
// EEPROM Layout & Session Struct
// ---------------------------------------------------------------------------
//  - [0..3]   : uint32_t sessionCount
//  - [4..end] : session data in blocks of 12 bytes each
//
// Each session block: 
//    Byte 0..3  : start time (Big-endian)
//    Byte 4..7  : stop time  (Big-endian)
//    Byte 8..11 : steps      (Big-endian)

struct TreadmillSession {
  uint32_t start;
  uint32_t stop;
  uint32_t steps;
};

// ---------------------------------------------------------------------------
// EEPROM Read/Write Helpers
// ---------------------------------------------------------------------------
uint32_t getSessionCountFromEEPROM() {
  uint32_t count = 0;
  count |= (EEPROM.read(0) << 24);
  count |= (EEPROM.read(1) << 16);
  count |= (EEPROM.read(2) << 8);
  count |= EEPROM.read(3);
  return count;
}

void setSessionCountInEEPROM(uint32_t count) {
  EEPROM.write(0, (count >> 24) & 0xFF);
  EEPROM.write(1, (count >> 16) & 0xFF);
  EEPROM.write(2, (count >> 8) & 0xFF);
  EEPROM.write(3, count & 0xFF);
}

TreadmillSession readSessionFromEEPROM(int index) {
  TreadmillSession session;
  int startAddress = 4 + (index * SESSION_SIZE_BYTES);

  session.start = ((uint32_t)EEPROM.read(startAddress)     << 24) |
                  ((uint32_t)EEPROM.read(startAddress + 1) << 16) |
                  ((uint32_t)EEPROM.read(startAddress + 2) <<  8) |
                   (uint32_t)EEPROM.read(startAddress + 3);

  session.stop  = ((uint32_t)EEPROM.read(startAddress + 4) << 24) |
                  ((uint32_t)EEPROM.read(startAddress + 5) << 16) |
                  ((uint32_t)EEPROM.read(startAddress + 6) <<  8) |
                   (uint32_t)EEPROM.read(startAddress + 7);

  session.steps = ((uint32_t)EEPROM.read(startAddress + 8)  << 24) |
                  ((uint32_t)EEPROM.read(startAddress + 9)  << 16) |
                  ((uint32_t)EEPROM.read(startAddress + 10) <<  8) |
                   (uint32_t)EEPROM.read(startAddress + 11);

  return session;
}

void writeSessionToEEPROM(int index, TreadmillSession session) {
  int startAddress = 4 + (index * SESSION_SIZE_BYTES);

  // Write start
  EEPROM.write(startAddress,     (session.start >> 24) & 0xFF);
  EEPROM.write(startAddress + 1, (session.start >> 16) & 0xFF);
  EEPROM.write(startAddress + 2, (session.start >>  8) & 0xFF);
  EEPROM.write(startAddress + 3, (session.start      ) & 0xFF);

  // Write stop
  EEPROM.write(startAddress + 4, (session.stop >> 24) & 0xFF);
  EEPROM.write(startAddress + 5, (session.stop >> 16) & 0xFF);
  EEPROM.write(startAddress + 6, (session.stop >>  8) & 0xFF);
  EEPROM.write(startAddress + 7, (session.stop      ) & 0xFF);

  // Write steps
  EEPROM.write(startAddress + 8,  (session.steps >> 24) & 0xFF);
  EEPROM.write(startAddress + 9,  (session.steps >> 16) & 0xFF);
  EEPROM.write(startAddress + 10, (session.steps >>  8) & 0xFF);
  EEPROM.write(startAddress + 11, (session.steps      ) & 0xFF);
}
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

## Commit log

2025-02-02 Initial commit - currently arduino/app work together to downloads saved simulated sessions
2025-02-08 adding a folder to match sketch name as required by arduino ide.
2025-02-08 Switched to Nano ESP32, ntp.h, lcd code stubbed out
2025-02-08 RETRO_MODE, brought in a basic uart req/resp processor.
    At the moment, it's missing characters periodically. I suspect either the wifi code or bluetooth handlers are adding loop delay?
    [lifespan-ble-proxy.ino]
2025-02-09 session count, idle vs active lcd, session printing
    - fixed bug in session printing.
    [lifespan-ble-proxy.ino]
2025-02-09 ios app now writes to healhkit after sync.
    - Currently has some ble protocol things to workout.
2025-02-09 [arduino] BLE done marker / LCD_ENABLED
2025-02-14 [arduino] keeps track of "today's steps"
2025-02-15 fritz sketch i used to make serial schematic
    [serial-thing.fzz]
2025-02-15 refactoring deviceConnected, more console commands implemented.
2025-02-16 Changed the BLE Service URLS to avoid conflicts
    [lifespan-ble-proxy.ino]
2025-02-16 No Treadspan devices found msg.
2025-02-17 Full port to NimBLE.
    - Ported because with original implementation i was seeing callbacks for the BLE Server getting invoked when the client connected (or perhaps it was the reverse)... the point is the callbacks were being invoked when they shouldn't have been.
    - Still believe there is some stability connections issues here. Was experiencing last night the mobile app disconnecting due to timeouts. Haven't reproduced yet today.
    [lifespan-ble-proxy.ino]
2025-02-18 metrics bugs
    - One never allow it to display dates in the future.
    - if you open the metrics view and go to the W tab (Week). If it’s before 7pm ET the farthest right item will be yesterday. This issue might be included in other views as well.
    - the day view x axis is really broken. Not displaying the right labels.
    - Under each graph (except the Today graph) display the average number of steps per day, and what percent come from Treadmill sources.
2025-02-19 WifiCreds from EEPROM, main loop refactoring. ImprovSerial - (doesn't work though)
    [lifespan-ble-proxy.ino]
2025-02-22 TFTScreens
    - Splash, NoWifi, Running screens
    - Optimized Program Space by removing/shortening console logs.
    [lifespan-ble-proxy.ino]
2025-02-23 FAQ View v1, currently has compile issue.
2025-02-23 Arduino IDE setup.
2025-02-26 BLE robustness, start duration
    - ~~Make BLE code very robust.~~
    - ~~Make BLE session end detection more robust, had issues where it thought it was "unknown";~~
    - ~~Don't start session until time is set? Or... once time is set calculate it from the session duration.~~
    - ~~Connecting to wifi screen on TFT.~~
    [lifespan-ble-proxy.ino]
2025-02-27 [esp32] BT Logo drawn with lines instead of image.
2025-02-28 splash page, improved faq
    [metrics] - multisources, removed arduino --> Treadspan
2025-02-28 [arduino] - bug fix in todays step count
    [lifespan-ble-proxy.ino]
2025-03-01 Renamed arduino folder name
2025-03-02 6M view - The selectedDataView should indicate the range in which you’re viewing. It only shows the start day right now. So, change it to be a range of start day - end day for that week selected.
2025-03-15 Time Characteristics - READ/WRITE
    IOS App - reads time, detects if it's off by more than 5 minutes and displays a warning message.
    IOS App waits for time response from device before subscribin to notifications
2025-03-15 ** Treadmill Device Class : Omni Console **
    - Made an TreadmillDevice class which can be extended.
2025-03-15 Retro Console "TreadmillDevice"
    - Code works on ArduinoNano ESP32
    - Although the mobile app portion syncs slower than I remember it in the past.
2025-03-16 *GET_TIME_THROUGH_NTP* and wifi reconnect
    Note: having an issue with omni console at the moment. going to revert to see if it was caused by recent change.
    [treadspan.ino]
2025-03-16 Fixed Omni console implementation.
    - removed setup code
    - redid loop handler.
    [treadspan.ino]
2025-03-16 finished renaming devices
2025-03-16 set sessionStart in case time wasnt set initially
2025-03-23 Debug stuff in the NTP Code, likely reverting
    [treadspan.ino]
2025-04-05 tweaks to make rtc mode work again and not display error message on lcd.
    [treadspan.ino]
2025-04-05 When unable to find Omni console, periodically chip reboots due to a crash. Attempts to mitigate by checking nullptr references.
    [TreadmillDeviceLifespanOmniConsole.h]
2025-04-06 DebugWrapper - printArray method.
2025-04-06 FTMS is now resetting on urevo, debug method prints full characteristic map. bottom button sends reset.
    [TreadmillDeviceFTMS.h, treadspan.ino]
2025-04-19 renamed arduino/treadspan to arduino/src to be compatible with platformio.
    - platformio.ini
2025-04-20 First UREVO Proprietary impl that works.
    - #ifdef VERBOSE_LOGGING
    - abstract printCharacteristicAndHandleMap
    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
2025-04-26 Basic BLE 180A Device Info fetcher.
2025-04-26 UREVO. Resubs after sending reset command
    [TreadmillDeviceUrevoProtocol.h]
2025-04-26 updated platform.ini with additional board settings and builds map file also.
